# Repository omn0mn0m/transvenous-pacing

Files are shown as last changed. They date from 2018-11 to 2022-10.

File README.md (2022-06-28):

# transvenous-pacing




BME Capstone Project

This code is meant to work with [transvenous-pacing-gui](https://github.com/omn0mn0m/transvenous-pacing-gui).

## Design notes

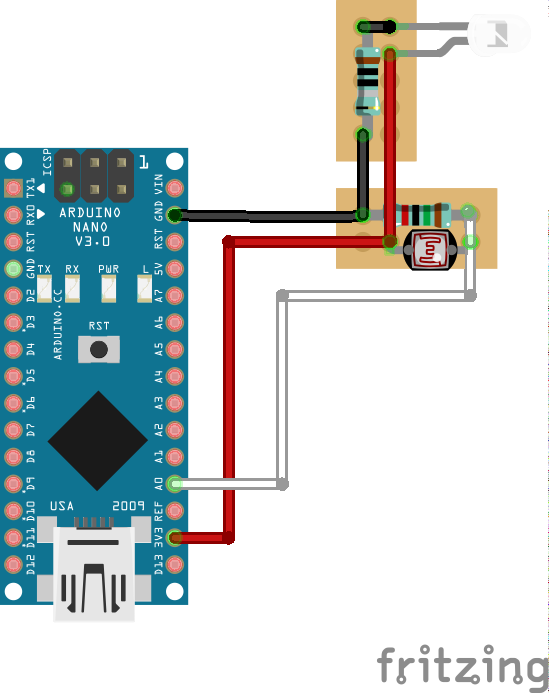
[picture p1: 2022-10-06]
schematics/Perfboard_bb.png

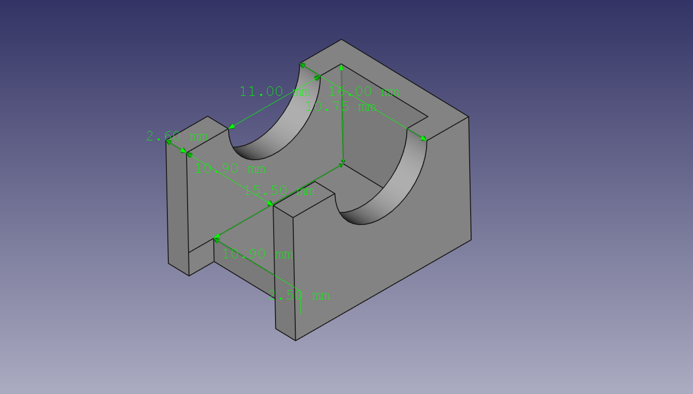
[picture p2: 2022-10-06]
models/dimensions.png

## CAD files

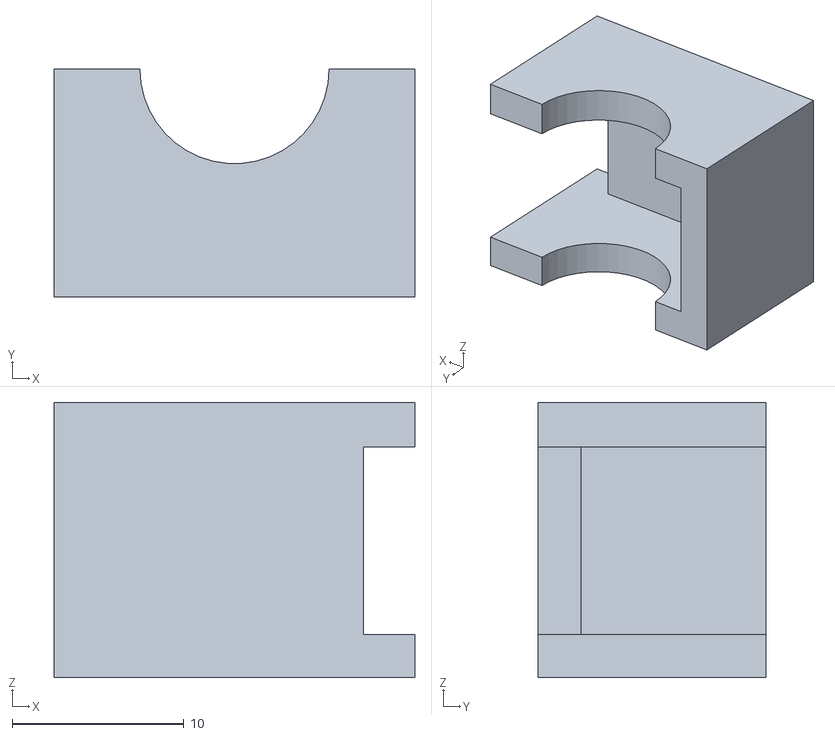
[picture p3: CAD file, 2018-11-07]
models/sensor-mount-2.stl
21.0 x 13.2 x 16.0

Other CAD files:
models/sensor-mount.fcstd
models/sensor-mount.stl

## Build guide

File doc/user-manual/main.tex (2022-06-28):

\documentclass[12pt, titlepage]{article}
\usepackage[utf8]{inputenc}
\usepackage[margin=1.0in]{geometry}

\title{Balloon Catheter Training Device User Manual}
\author{Nam Tran\\ Biomedical Engineering\thanks{Undergraduate}, The George Washington University}
\date{November 2018}

\usepackage[english]{babel}
\usepackage{graphicx}
\usepackage{float}
\usepackage{forest}

\usepackage[parfill]{parskip}

\begin{document}

\maketitle

\section{Introduction}
Balloon catheterization in this case is used for transvenous cardiac pacing, often utilised in the emergency department. This user manual describes a step-by-step narrative for using the device, referencing the objectives, functions, and user stories determined for this product. All user stories, objectives, and functions can be found in "Backgrounds, Vision, and Needs" \cite{backgroundreport}. They are also summarised in the appendix at the end of the document.

\section{Narrative}

\subsection{Installation}

All necessary software for the training model are packaged on the provided USB drive. The USB drive is organised as follows:

\begin{forest}
  for tree={
    font=\ttfamily,
    grow'=0,
    child anchor=west,
    parent anchor=south,
    anchor=west,
    calign=first,
    edge path={
      \noexpand\path [draw, \forestoption{edge}]
      (!u.south west) +(7.5pt,0) |- node[fill,inner sep=1.25pt] {} (.child anchor)\forestoption{edge label};
    },
    before typesetting nodes={
      if n=1
        {insert before={[,phantom]}}
        {}
    },
    fit=band,
    before computing xy={l=15pt},
  }
[Balloon-Catheter
  [Installation
    [GUI-Install.msi]
  ]
  [Documentation
    [User-Manual.pdf]
    [Licenses.pdf]
  ]
]
\end{forest}

Prior to use, the software should be installed by running the installation files found under "Installation". As of the writing of this manual, the only necessary software to download is the GUI software for interfacing with the training model.

\subsection{Training Set-Up}

Prior to the training exercise, the instructor should have the device connected to the school's wireless network (similar to a wireless printer). On the training room control computer, open the GUI software and mirror it to the training room's hospital monitor. This process can be assisted by the school's IT department. The GUI will request that you choose which training model to display for (in case of multiple training exercises being conducted at once). The GUI will indicate when the training model is calibrated and ready for use.

\begin{figure}[H]
\centering
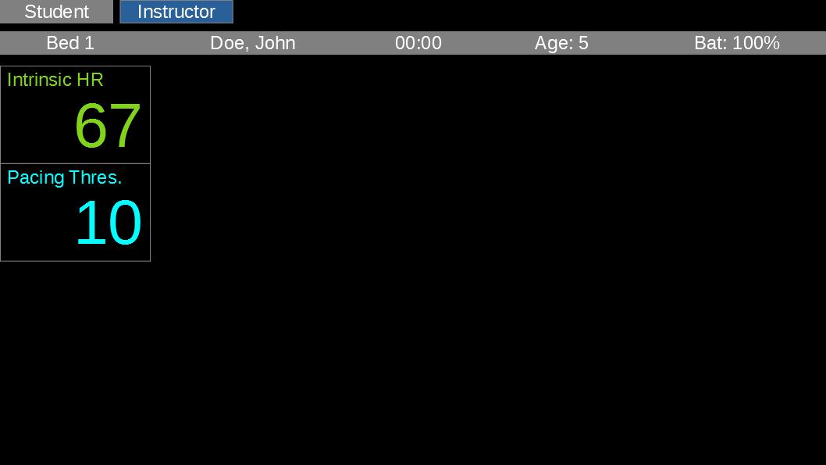
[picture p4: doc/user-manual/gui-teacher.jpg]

\caption{Instructor GUI screen for setting simulation options}
\label{fig:teacher}
\end{figure}

At any time, the instructor is able to input a starting intrinsic heart rate for the training model to display (Figure \ref{fig:teacher}). This will automatically show on the GUI when the catheter is inserted into the model. The instructor is also able to set a pacing threshold for the pacer to reach at any time as well.

\subsection{General Use}
You will begin the training using a balloon catheter and pacer provided by your instructor. These are outside of the scope of what this training device includes. From there, follow the instructor's direction on the actual medical procedure. This procedure is standard and outside of the scope of operating our training device specifically.

\begin{figure}[H]
\centering
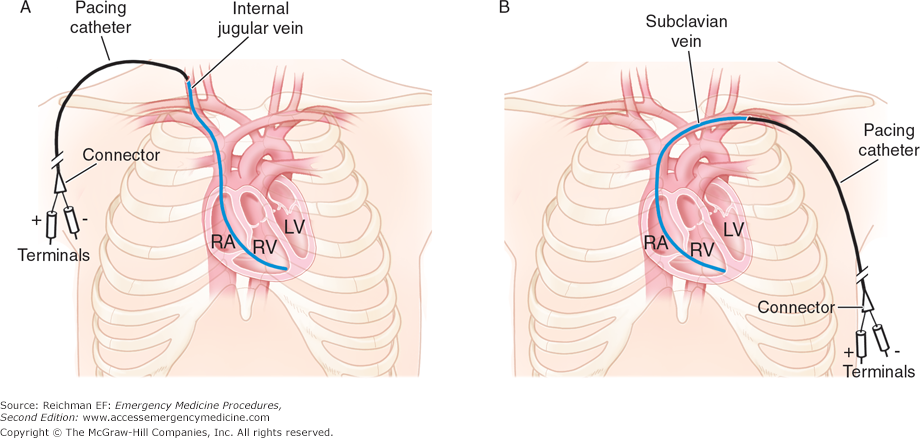
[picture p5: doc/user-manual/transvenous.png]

\caption{Catheter path through the jugular vein and subclavian vein \cite{reichman2013emprocedures}}
\label{fig:procedure}
\end{figure}

The training device will not provide feedback until the catheter has been inserted into the jugular vein (For reference, please see Figure \ref{fig:procedure}). As specified in User Stories 1 and 2, Objectives 2, 4, and 6, and Functions 1, 2, and 3; the simulation room monitor will display an ECG (Figure \ref{fig:student}).

\begin{figure}[H]
\centering
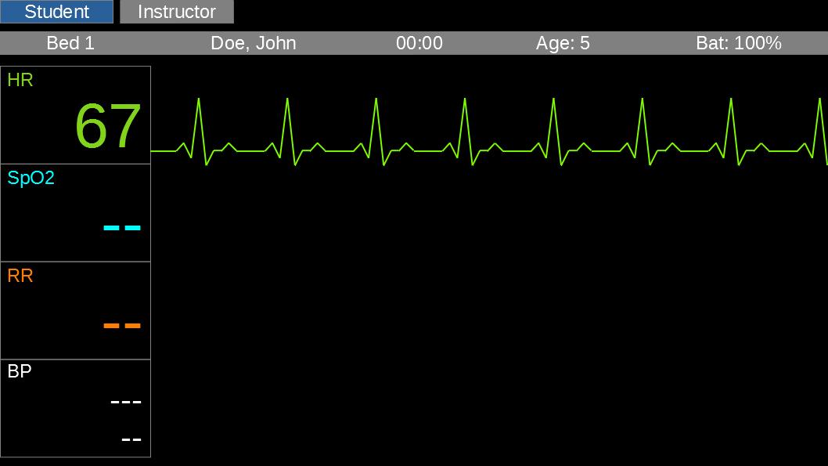
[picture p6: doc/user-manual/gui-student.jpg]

\caption{Student GUI screen that is designed to simulate the look of an actual vital signs monitor}
\label{fig:student}
\end{figure}

This ECG signal will change at the different landmarks along the catheter's path. These landmarks are the upper, mid, and lower right atrium; upper, mid, and lower right ventricle, pulmonary artery, superior vena cava, and inferior vena cava (Objective 4). If the signal is indicating the position is at the pulmonary artery or inferior vena cava, you have missed the ventricle and should back out to try again.

Once the ECG displays the signal for the lower right ventricle (see your instructor for example of this signal), begin to pace the catheter using the pacer. The ECG will show spikes when the pacer is sending a current (User Story 6). The instructor will have set a current threshold for when the heart will polarise prior to the training exercise (User Story 5, Objective 3). If the threshold is not reached, increase the current on the pacer.

When the instructor is satisfied with student performance, the training model can be reset by removing the catheter and any medical interventions. The GUI will be reset to its original state automatically upon catheter removal.

\clearpage
\section{Appendix}

\subsection{User Stories}
The following user stories were derived from the needs presented by our client, Dr. Claudia Ranniger \cite{sprintlog}.

\begin{enumerate}
  \item Determine ECG morphology based on catheter location in the relevant vasculature region
  \item Display ECG while catheter is moving
  \item Connect catheter to pacer device to communicate location and for pacing stimulation
  \item Allow student to set pacing frequency and current
  \item Allow instructor to set pacing current threshold and initial beats per minute
  \item Determine how ECG responds to pacer settings (current and beats per minute)
\end{enumerate}

\subsection{Objectives}
The following objectives were considered in the engineering design of the device \cite{backgroundreport}.

\begin{enumerate}
  \item Be easy to interface with for the instructor
  \item Be able to display signal on trainer room monitor
  \item Be able to have the instructor set a pacing threshold (in mA and frequency)
  \item Be able to indicate to the student the current location of the catheter as they move toward RV wall
  \item Be able to illustrate physiological variability in interval duration and wave amplitudes
  \item Contain morphological accurate signals
  \item Be able to accurately determine catheter location during times of increased motion (e.g. shaking due to nervousness)
\end{enumerate}

\subsection{Functions}
The following functions were required to meet our objectives \cite{backgroundreport}.

\begin{enumerate}
  \item Detect catheter position
  \item Display a continuous ECG signal based on the location of the balloon catheter
  \item Detect and display the corresponding signal when the catheter is between two sensors
  \item Generate an ECG signal based on heart rate chosen by instructor
  \item Generate an ECG signal based on current catheter location and heart rate
\end{enumerate}

\clearpage
\bibliographystyle{ieeetr}
\bibliography{references}

\end{document}

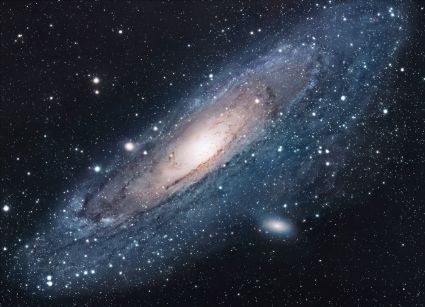
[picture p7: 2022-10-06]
doc/user-manual/universe.jpg

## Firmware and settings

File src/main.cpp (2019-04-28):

/**
 * know when sensor is going from one to another
 * track if the position has gone forward or backwards
 *
 * know distance
 * know it works
 * know failures in communications
 */

#include <Arduino.h>
#include <BluetoothSerial.h>

#include "config.h"

// Positions
#define POS_UHOH        0x30 // 0
#define POS_SVC         0x31 // 1
#define POS_UP_ATR      0x32 // 2
#define POS_MID_ATR     0x33 // 3
#define POS_LOW_ATR     0x34 // 4
#define POS_VEN         0x35 // 5
#define POS_VEN_WALL    0x36 // 6

// Serial Commands
#define COM_RECALIBRATE 0x43 // C
#define COM_GET_POS 0x47 // G

// Global Variables
BluetoothSerial SerialBT;

struct ir_sensor {
    int     pin;
    uint16_t avg_reading;
    uint16_t ambient_lvl;
};

struct ir_sensor ir_0 = {PORT_IR_0, 0, 0};
struct ir_sensor ir_1 = {PORT_IR_1, 0, 0};
struct ir_sensor ir_2 = {PORT_IR_2, 0, 0};
struct ir_sensor ir_3 = {PORT_IR_3, 0, 0};
struct ir_sensor ir_4 = {PORT_IR_4, 0, 0};
struct ir_sensor ir_5 = {PORT_IR_5, 0, 0};

uint8_t prev_pos = POS_UHOH;

// Global Functions
void ir_init(struct ir_sensor *ir);
uint16_t get_moving_average(struct ir_sensor *ir);
void write_out(char data);
int get_available_bytes();
char read_in();
void read_command();
void update_position();

/**
 *  Initialisation code
 */
void 
setup() {
  // put your setup code here, to run once:
  if (USE_BT) {
    SerialBT.begin("Phantom");
  } else {
    Serial.begin(BAUD_RATE);
  }

  ir_init(&ir_0);
  ir_init(&ir_1);
  ir_init(&ir_2);
  ir_init(&ir_3);
  ir_init(&ir_4);
  ir_init(&ir_5);

  if (USE_BT) {
    SerialBT.println("Initialised");
    SerialBT.print(POS_UHOH);
  } else {
    Serial.println("Initialised");
    Serial.print(POS_UHOH);
  }
}

/**
 *  Main loop for the microcontroller
 */
// LCOV_EXCL_START
void 
loop() {
  // put your main code here, to run repeatedly:
  read_command();
  update_position();
}

void
read_command() {
  int bytes_incoming = get_available_bytes();

  if (bytes_incoming > 0) {
    uint8_t command_char = read_in();
    
    switch (command_char) {
      case COM_RECALIBRATE:
        ir_init(&ir_0);
        ir_init(&ir_1);
        ir_init(&ir_2);
        ir_init(&ir_3);
        ir_init(&ir_4);
        ir_init(&ir_5);
        break;
      case COM_GET_POS:
        write_out(prev_pos);
        break;
      default:
        if (USE_BT) {
          SerialBT.println("Err: " + command_char);
        } else {
          Serial.println("Err: " + command_char);
        }
        break;
    }
  }
}

void
update_position() {
  ir_0.avg_reading = get_moving_average(&ir_0);
  ir_1.avg_reading = get_moving_average(&ir_1);
  ir_2.avg_reading = get_moving_average(&ir_2);
  ir_3.avg_reading = get_moving_average(&ir_3);
  ir_4.avg_reading = get_moving_average(&ir_4);
  ir_5.avg_reading = get_moving_average(&ir_5);
  
  if (ir_5.ambient_lvl - ir_5.avg_reading >= THRESHOLD) {
    if (prev_pos != POS_VEN_WALL) {
      prev_pos = POS_VEN_WALL;
      write_out(POS_VEN_WALL);
    }
  } else if (ir_4.ambient_lvl - ir_4.avg_reading >= THRESHOLD) {
    if (prev_pos != POS_VEN) {
      prev_pos = POS_VEN;
      write_out(POS_VEN);
    }
  } else if (ir_3.ambient_lvl - ir_3.avg_reading >= THRESHOLD) {
    if (prev_pos != POS_LOW_ATR) {
      prev_pos = POS_LOW_ATR;
      write_out(POS_LOW_ATR);
    }
  } else if (ir_2.ambient_lvl - ir_2.avg_reading >= THRESHOLD) {
    if (prev_pos != POS_MID_ATR) {
      prev_pos = POS_MID_ATR;
      write_out(POS_MID_ATR);
    }
  } else if (ir_1.ambient_lvl - ir_1.avg_reading >= THRESHOLD) {
    if (prev_pos != POS_UP_ATR) {
      prev_pos = POS_UP_ATR;
      write_out(POS_UP_ATR);
    }
  } else if (ir_0.ambient_lvl - ir_0.avg_reading >= THRESHOLD) {
    if (prev_pos != POS_SVC) {
      prev_pos = POS_SVC;
      write_out(POS_SVC);
    }
  } else {
    if (prev_pos != POS_UHOH) {
      prev_pos = POS_UHOH;
      write_out(POS_UHOH);
    }
  }
}
// LCOV_EXCL_STOP 

/**
 * Calculates the first average and ambient level for the sensor
 * 
 * @param ir Pointer to a sensor struct
 */
void 
ir_init(struct ir_sensor *ir) {
    uint32_t sum_samples = 0;

    for (uint8_t i = 0; i < SAMPLE_SIZE; i++) {
        sum_samples += analogRead(ir->pin);
        if (USE_BT) {
          SerialBT.println(sum_samples);
        } else {
          Serial.println(sum_samples);
        }
        
        delay(50);
    }

    ir->avg_reading = sum_samples / SAMPLE_SIZE;
    ir->ambient_lvl = ir->avg_reading;

    if (USE_BT) {
      SerialBT.println("Calibrated!");
    } else {
      Serial.println("Calibrated!");
    }
}

/**
 * Returns an exponential moving average
 * (more like an IIR filter than anything else though)
 * 
 * @param ir_sensor The sensor to read from
 * 
 * @return Moving Average 
 */
uint16_t
get_moving_average(struct ir_sensor *ir) {
    uint16_t moving_avg = ((ir->avg_reading * (SAMPLE_SIZE - 1)) + analogRead(ir->pin)) / SAMPLE_SIZE;

    return moving_avg;
}

void
write_out(char data) {
  if (USE_BT) {
    SerialBT.write(data);
  } else {
    Serial.write(data);
  }
}

int
get_available_bytes() {
  if (USE_BT) {
    return SerialBT.available();
  } else {
    return Serial.available();
  }
}

char
read_in() {
  if (USE_BT) {
      return SerialBT.read();
    } else {
      return Serial.read();
    }
}

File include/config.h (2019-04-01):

#ifndef CONFIG_H_
#define CONFIG_H_

// Software Constants
#define THRESHOLD 450

// Hardware Constants
// #define PORT_IR_0 36
// #define PORT_IR_1 39
// #define PORT_IR_2 34
// #define PORT_IR_3 35
// #define PORT_IR_4 32
// #define PORT_IR_5 33
// #define PORT_IR_6 25
// #define PORT_IR_7 26
// #define PORT_IR_8 27

#define PORT_IR_0 36
#define PORT_IR_1 39
#define PORT_IR_2 34
#define PORT_IR_3 35
#define PORT_IR_4 32
#define PORT_IR_5 33

#define PC_SERIAL_TX USBTX
#define PC_SERIAL_RX USBRX

#define BAUD_RATE    9600
#define USE_BT       1

// Variable Constants
#define SAMPLE_SIZE 8

#endif // CONFIG_H_

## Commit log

2018-10-24 Working 3 sensor (and potentially more) setup
2018-10-31 Added and commented out future sensors
2018-10-31 Added perfboard design
    [Perfboard.fzz]
2018-11-06 Added 3d model
    [sensor-mount.fcstd, sensor-mount.stl]
2018-11-07 Added more sensors and added command pipe
2018-11-07 Updated sensor mount
    [sensor-mount-2.stl, sensor-mount.fcstd, sensor-mount.stl]
2019-01-28 Switched to bluetooth
2019-03-31 Pins moved to avoid DAC pin (for BT)
    [config.h]
2022-10-06 [ImgBot] Optimize images
    *Total -- 165.87kb -> 136.95kb (17.44%)
    /models/dimensions.png -- 63.88kb -> 44.96kb (29.61%)
    /schematics/Perfboard_bb.png -- 74.48kb -> 65.62kb (11.9%)
    /doc/user-manual/universe.jpg -- 27.51kb -> 26.37kb (4.15%)
